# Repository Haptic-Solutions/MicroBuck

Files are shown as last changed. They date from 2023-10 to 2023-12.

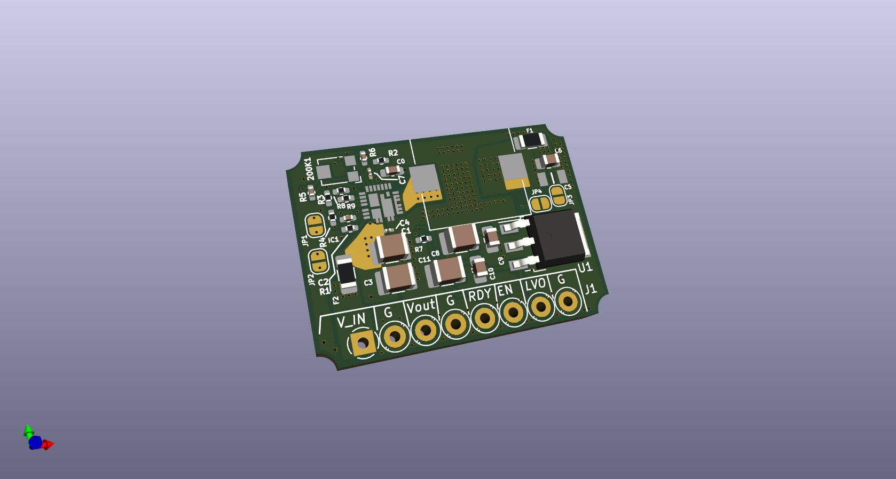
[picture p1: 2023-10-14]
board.png

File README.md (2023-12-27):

Open source under the https://creativecommons.org/licenses/by-nc/4.0/ to be used for personal projects.
However, if you would like to use it for commercial use please feel free to reach out to peter@hapticsol.com to negotiate a low cost license fee.

Dual output adjustable power supply based off of the SIC431 chip for high current output in a very small form factor and end-user choice of linear side regulator for low ripple output or standby power.

Applications: 
Robotics.
Portable and wearable electronics.
Low or high power applications.
Battery powered electronics.
Custom built small compute devices.

Features:
Dual output, switching and linear.
SIC431 based switching side.
End-user choice of linear regulator.
Tuneable or programmable switching side voltage output via potentiometer or bypass jumper.
Daisy-chain or fully separate supply to linear regulator configured by solderable jumpers.
Enable/Disable pin for switching side with optional pull up/down resistor pads.
VReady pin from switching side for sensitive electronics.

Warning: Higher Amperage draw will cause the board to reach temperatures not suitable for direct skin contact. An enclosure to prevent direct contact and a heatsink with sufficient cooling air should be used to reduce working temperature.

If you would like to purchase one from us you can find it on our website here:
https://hapticsol.com/power-electronics/micro-psu

Data Sheet: https://hapticsol.com/s/Micro-PSU-V0_0-Datasheet.pdf

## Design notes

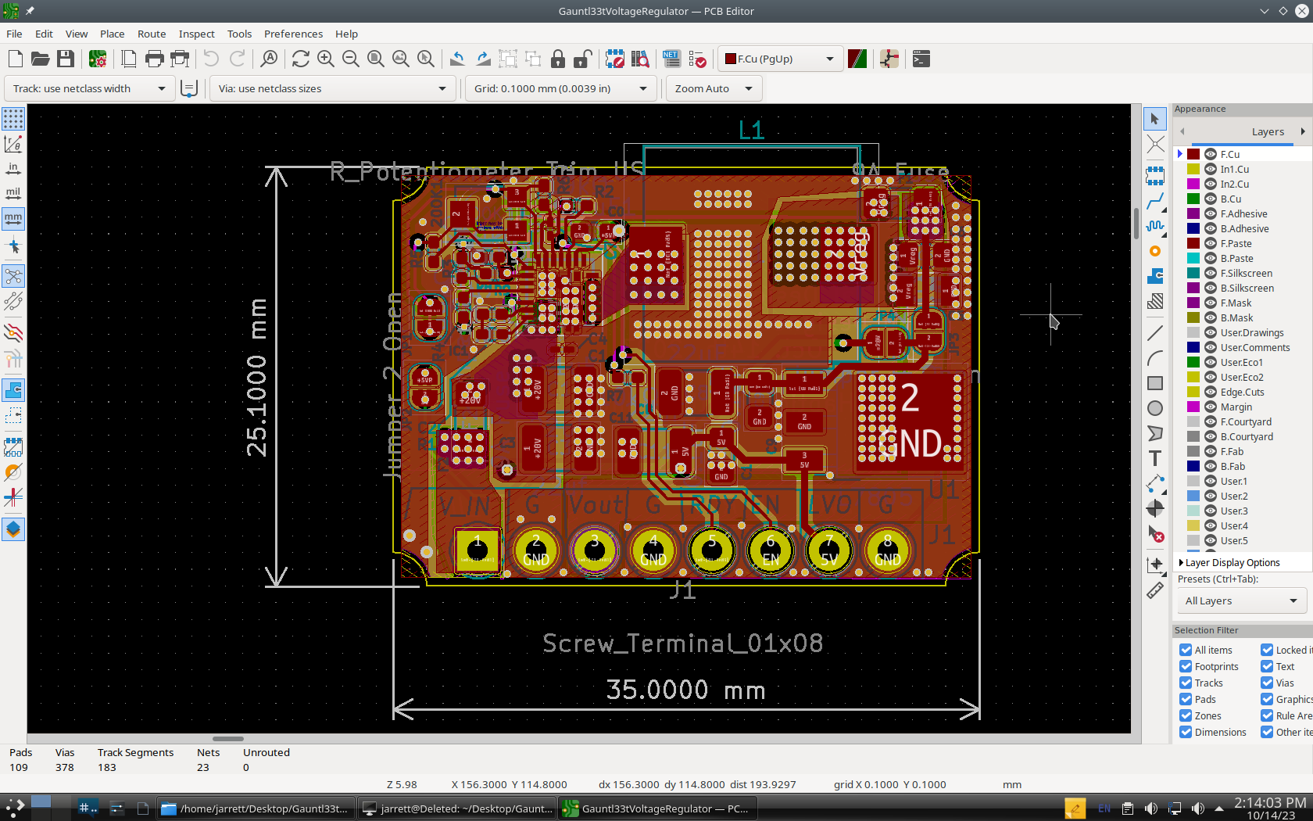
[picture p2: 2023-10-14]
Screenshot_20230914_200438.png

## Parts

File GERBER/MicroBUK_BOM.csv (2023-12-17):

Component Count: | 23
Item | Qty | Reference(s) | Value | Component ID
1 | 1 | 200K1 | 200K | TC33X-2-204ECT-ND
2 | 1 | C0 | 4.7uF | CL10B475KQ8NQNC
3 | 4 | C1,C3,C8,C11 | 22uF | CL32A226KAJNNNE
4 | 1 | C2 | 0.1uF | GRM155C71H104JE19J
5 | 1 | C4 | 0.1uF | 0201S104K250CT
6 | 1 | C5 | 47uF | EMK316BBJ476ML-T
7 | 3 | C6,C9,C10 | 0.1uF | C0805C104K5RAC7411
8 | 1 | C7 | 1uF | CC0201KRX5R5BB105
9 | 2 | F1,F2 | 10A | C1H10
10 | 1 | IC1 | SIC431 | SiC431AED-T1-GE3
11 | 1 | R1 | 1R | RK73H1ETTP1R00F
12 | 4 | R2,R5,R6,R7 | 10K | CR0402AFX-1002GAS
13 | 2 | R3,R4 | 51K | RMC1/16S-513JTH

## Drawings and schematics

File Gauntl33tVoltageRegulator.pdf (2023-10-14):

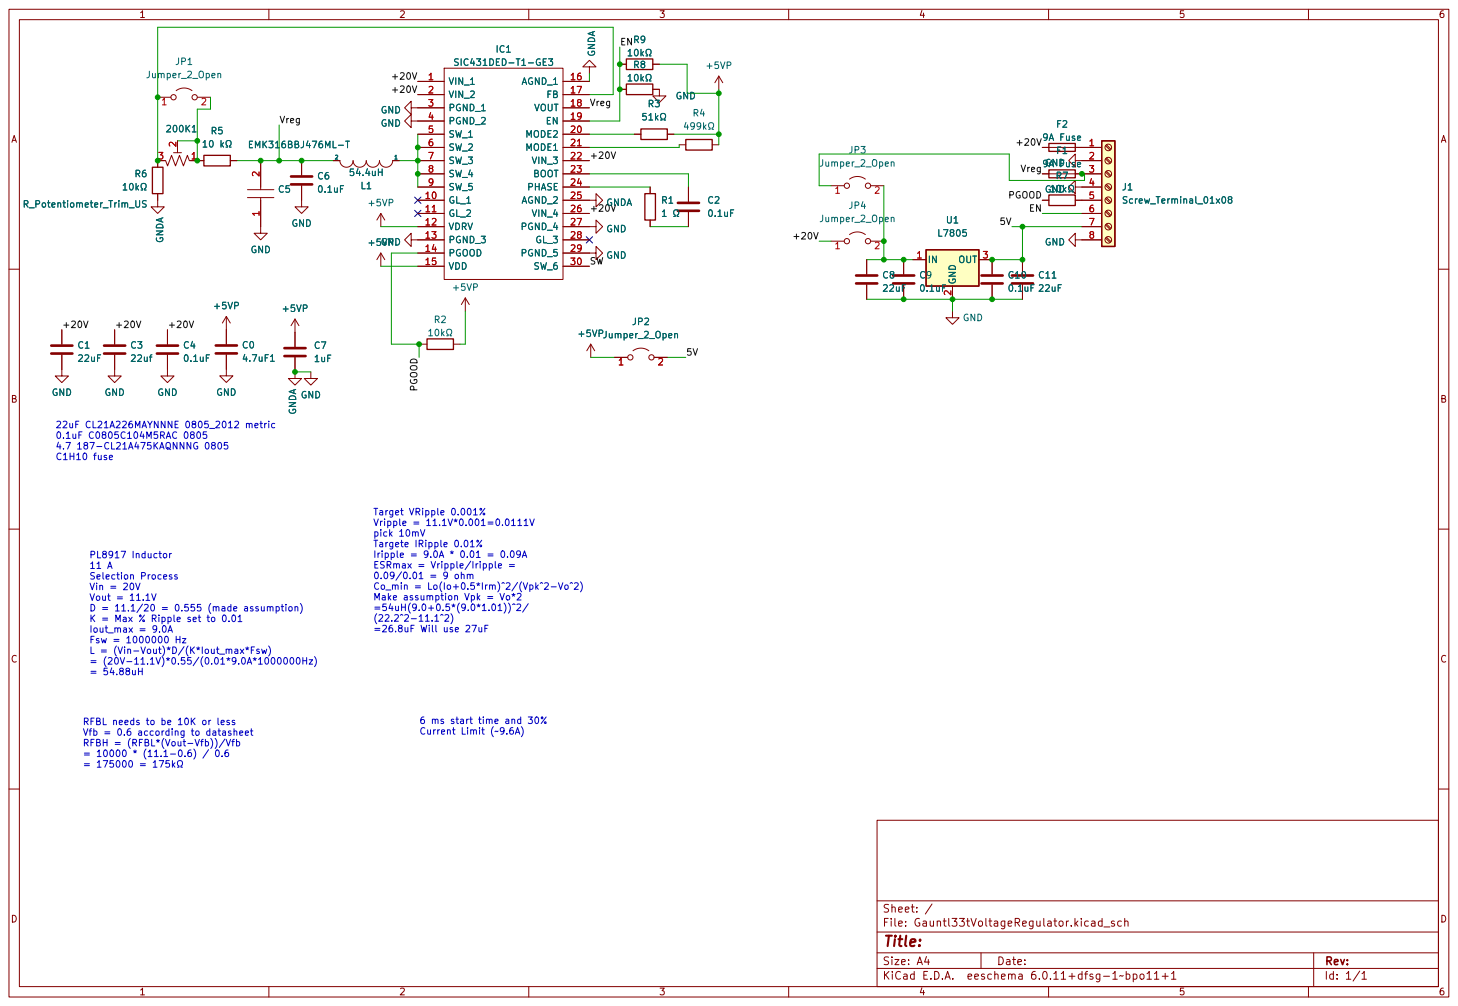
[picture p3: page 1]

6 ms start time and 30%
Current Limit (~9.6A)

Id: 1/1 Title: File: Gauntl33tVoltageRegulator.kicad_sch Sheet: /

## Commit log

2023-09-13 Added jumper pads for easy config changes and moved some things around.
    [Gauntl33tVoltageRegulator-B_Cu.gbr, Gauntl33tVoltageRegulator-B_Mask.gbr, Gauntl33tVoltageRegulator-B_Paste.gbr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]
2023-09-13 Update pdf, gerber, and drill files.
    [Gauntl33tVoltageRegulator-B_Cu.gbr, Gauntl33tVoltageRegulator-B_Mask.gbr, Gauntl33tVoltageRegulator-B_Paste.gbr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]
2023-09-15 added renders. added measurments to board design.
    [Gauntl33tVoltageRegulator.kicad_pcb]
2023-10-14 Update to larger Inductor.
    [Gauntl33tVoltageRegulator.kicad_pcb, Gauntl33tVoltageRegulator.kicad_sch]
2023-10-14 Added vias for secondary high-current paths. Adjusted solder mask in some areas. Updated and adjusted silk screening and text. Added pull-down resistor pad for chip enable. Changed pin6 ground connec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
    [Gauntl33tVoltageRegulator-B_Cu.gbr, Gauntl33tVoltageRegulator-B_Mask.gbr, Gauntl33tVoltageRegulator-B_Paste.gbr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]
2023-12-17 Update MicroBuk
    [Gauntl33tVoltageRegulator-B_Cu.gbr, Gauntl33tVoltageRegulator-B_Mask.gbr, Gauntl33tVoltageRegulator-B_Paste.gbr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]
